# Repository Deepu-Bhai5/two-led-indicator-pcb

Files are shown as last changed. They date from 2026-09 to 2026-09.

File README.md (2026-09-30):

# Two-LED Indicator PCB

A beginner PCB design project developed in KiCad as an introduction to
the complete PCB design workflow, from schematic capture to
manufacturing file generation.

## Overview

This project is a simple two-channel LED indicator PCB.

Each LED is independently controlled through its own current-limiting
resistor, with a common ground connection.

## Objectives

- Learn the KiCad PCB design workflow
- Create and validate a schematic
- Assign and work with through-hole footprints
- Design a two-layer PCB
- Route signal and ground connections
- Perform PCB Design Rule Checks (DRC)
- Generate Gerber and drill files
- Review the design using a manufacturer's DFM checker

## Circuit

The board uses:

- 1 × 3-pin input connector
- 2 × LEDs
- 2 × 200 Ω current-limiting resistors

### Connections

- J1 Pin 1 → R1 → D1 → GND
- J1 Pin 2 → R2 → D2 → GND
- J1 Pin 3 → GND

## Design

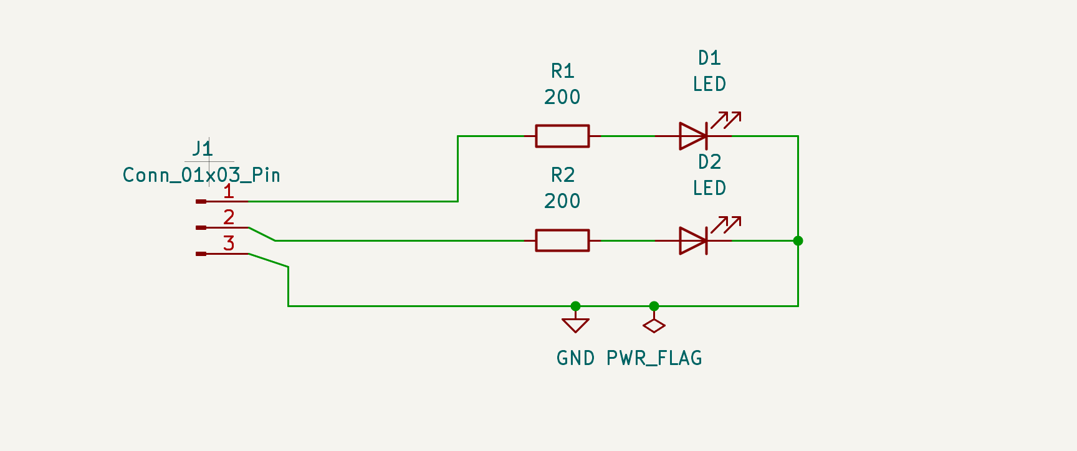
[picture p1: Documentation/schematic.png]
Schematic


## PCB Layout

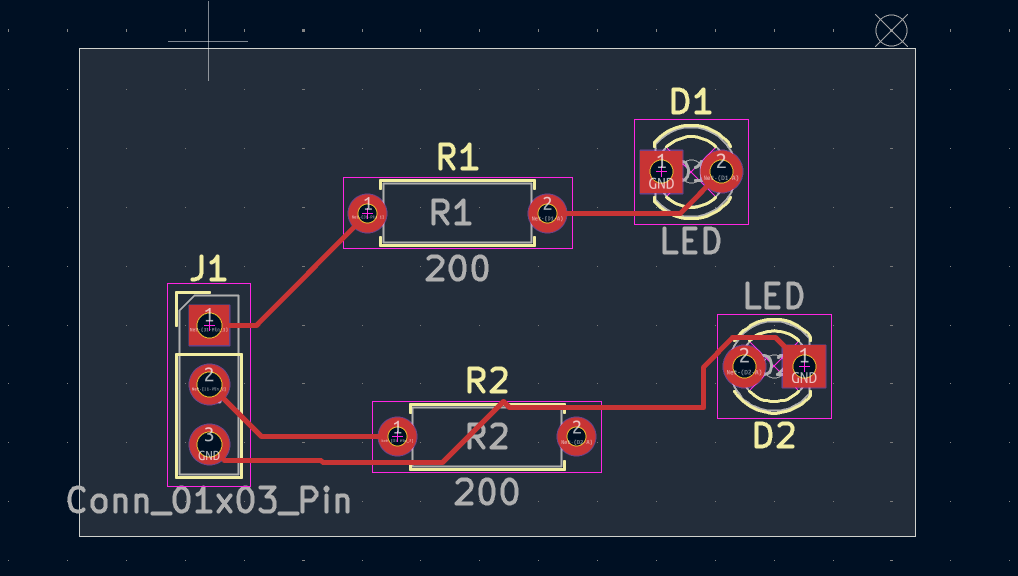
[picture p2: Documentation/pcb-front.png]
PCB Front


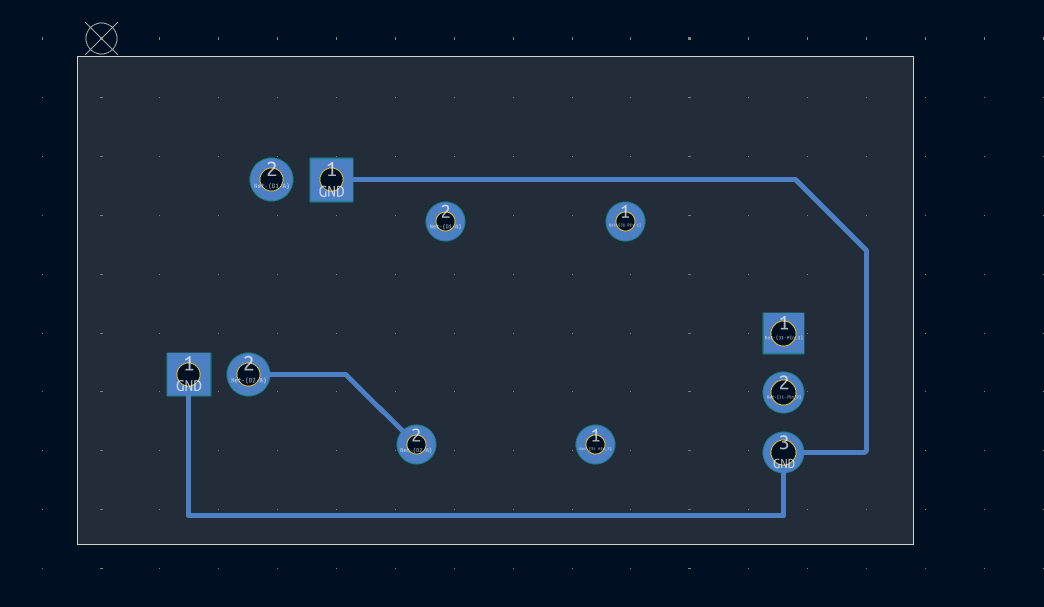
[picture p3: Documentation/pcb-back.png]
PCB Back


## 3D View

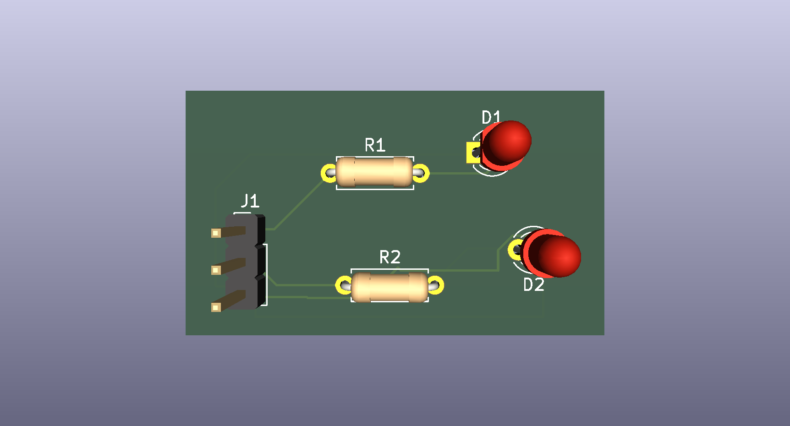
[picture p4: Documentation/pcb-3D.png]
3D View


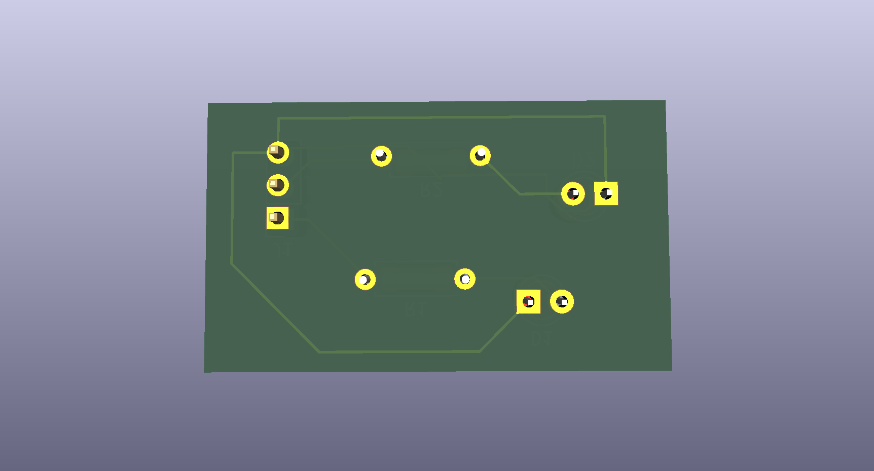
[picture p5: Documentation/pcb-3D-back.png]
3D View Bottom


## Design Validation

The PCB was checked using KiCad's Design Rule Checker.

Validation included:

- Connectivity
- Unconnected items
- Track clearances
- Footprint geometry
- PCB outline
- Manufacturing constraints

## Manufacturing

Gerber and drill files were generated using KiCad's manufacturing
output tools.

The final PCB design was evaluated using external Design for
Manufacturing (DFM) tools. The design passed checks covering:

- Copper trace width and spacing
- Solder mask
- Silkscreen
- Pad and annular ring geometry
- Drill spacing and drill-to-copper clearance
- Copper-to-board-edge clearance

The design is currently ready for PCB fabrication. Physical fabrication,
assembly, and electrical testing are pending.
## Problems Encountered

During development, several issues were identified and corrected,
including:

- Incorrect connector footprint selection
- LED polarity verification
- PCB routing issues
- Ground routing clearance
- PCB outline validation
- Solder-mask expansion requirements identified during DFM review

These issues were resolved through iterative PCB inspection and
validation.

## What I Learned

- KiCad schematic-to-PCB workflow
- Through-hole footprint selection
- PCB component placement
- Copper routing
- Ground routing
- PCB DRC
- Gerber generation
- Basic PCB manufacturing constraints
- DFM-based design iteration

## Future Improvements

- Fabricate and test the PCB
- Add input protection
- Explore a more compact PCB layout
- Develop a more functional LED indicator circuit
  
## Tools

- KiCad
- PCB manufacturer's DFM checker
- [JLCDFM](https://jlcdfm.com/)

## Project Status

**Design:** Complete  
**Electrical validation:** Complete  
**KiCad DRC:** Passed  
**Manufacturing DFM:** Passed  
**Gerber files:** Generated  
**Fabrication status:** Ready for manufacturing  
**Physical testing:** Pending
## Specifications

| Parameter | Value |
|---|---|
| PCB Layers | 2 |
| Board Size | ~35.5 × 20.75 mm |
| Components | Through-hole |
| Resistors | 200 Ω × 2 |
| LEDs | 3 mm × 2 |
| Input Connector | 1×3, 2.54 mm |
| Board Thickness | 1.6 mm |
| Copper | 1 oz |

## Author

**Deep Das**  
B.Tech ECE Student at Delhi Technological University (DTU)

[LinkedIn Profile](https://www.linkedin.com/in/deep-das-03ad4882/)

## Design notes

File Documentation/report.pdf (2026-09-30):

## HQDFM Design for Manufacture(DFM) Report

### File name: 0000A1086856_1

Time: 2026-10-01Layer count:2 | PCB Thickness: 1.60 | Quantity: 5
mm

Approved items

Urgent Issues

Issue Items

0 | 0 | 0

Basic Board Specs

### Trace Width/Spacing 8.00/8.00mil+

### Milling Density

Surface Finish Area | 12.17%

Test Point Count

Panel Efficiency

The file size is small, which can affect the surface mount assembly process. It is recommended to have a size larger than 7*7cm. You can optimize the size by adding a process edge or increasing the panelization.

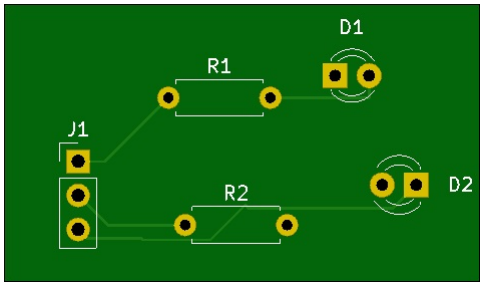
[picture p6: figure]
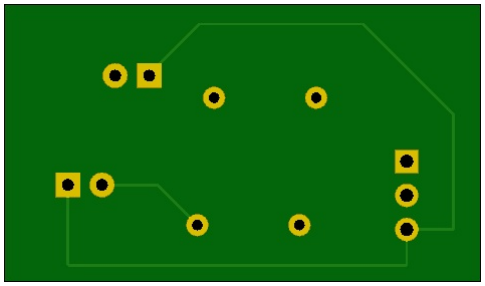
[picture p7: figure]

Type | Category | No. of Checks | Result
General Analysis | Ipc Check | 1
| Types Devices | 1
PCB_SOLDERMASK | Solder Mask Analysis | 4 | Pass
| Missing Mask Opening | 2 | Pass
PCB_SILKSCREEN | Silkscreen Analysis | 2 | Pass 3
| Signal Integrity | 5 | Pass 2
| Smallest Trace Width | 1 | Pass 2
| Smallest Trace Spacing | 4 | Pass 1
| SMD Pad Spacing | 2 | Pass
| Pad Size | 3 | Pass
| Annular Ring Size | 4 | Pass
| Drill to Copper | 4 | Pass
| Copper/Edge Gap | 3 | Pass
| Drill On Pad | 4 | Pass
| Special Pad | 1 | Pass 2
| Hatched Copper | 1 | Pass
| Drill Size | 14 | Pass 9
PCB_DRILL | Drill Spacing | 32 | Pass
| Drill to Edge | 4 | Pass
| Special Drills | 3 | Pass

### PCB_SIGNAL

ID | Check | Limits | Value | Issue | Image | Position | Qty | Level

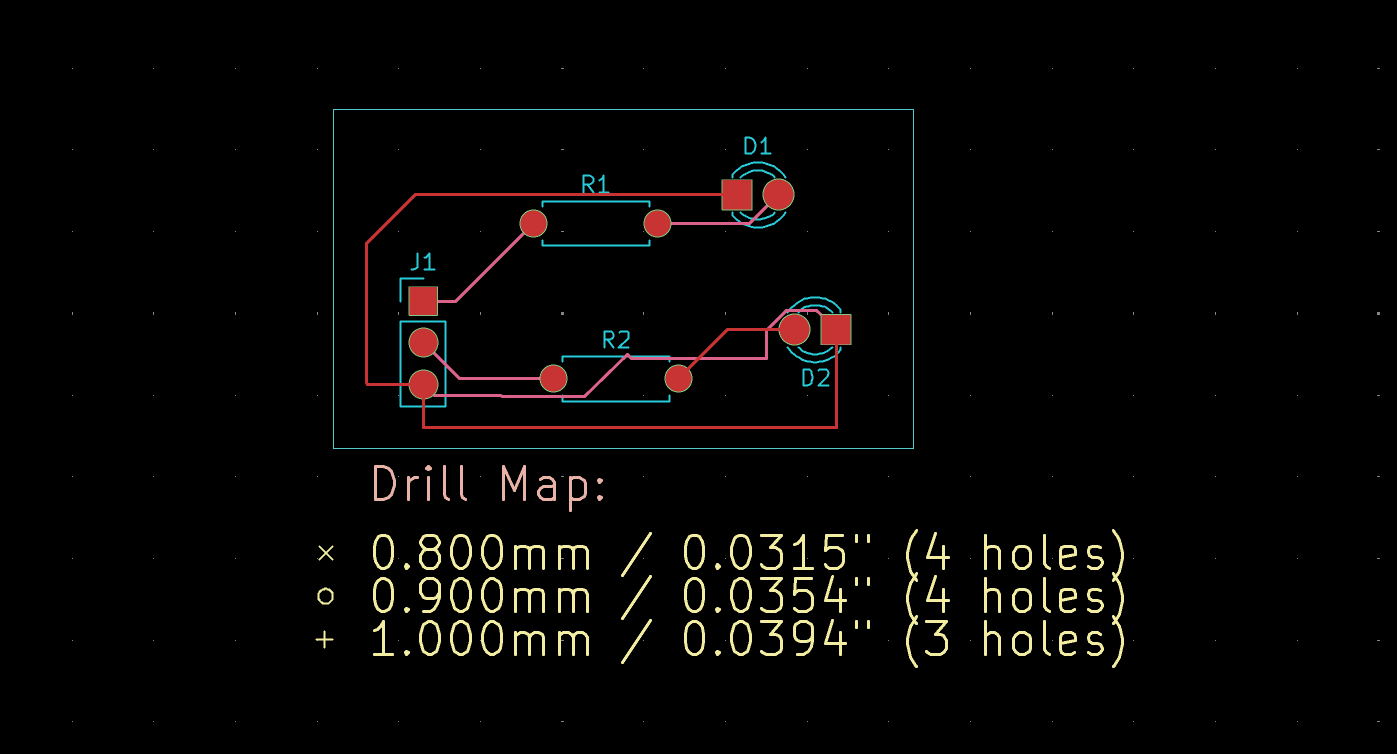
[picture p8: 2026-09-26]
Documentation/gerber-view.png

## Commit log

2026-09-26 Revise README for Two-LED Indicator PCB project
    Expanded the README to provide a detailed overview of the Two-LED Indicator PCB project, including objectives, circuit details, design validation, problems encountered, lessons learned, future improvements, tools used, and project status.
2026-09-26 Rename gerber view.png to gerber-view.png
2026-09-26 Rename pcb 3D.png to pcb-3D.png
2026-09-26 Rename pcb front.png to pcb-front.png
2026-09-26 Rename pcb back.png to pcb-back.png
2026-09-26 Create KiCad
2026-09-27 Add BOM csv file
    [two-led-indicator_BOM.csv]
2026-09-27 Rename pcb-3D back.png to pcb-3D-back.png
2026-09-30 Adding Gerber File
2026-09-30 Renaming Gerber zip file
2026-09-30 Update future improvements in README
    Removed 'Improve silkscreen layout' from future improvements.
